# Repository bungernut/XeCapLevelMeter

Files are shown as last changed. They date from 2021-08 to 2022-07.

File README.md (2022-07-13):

# XeCapLevelMeter

This is a demo board and Arduino code for the AD7151 chip:  https://www.analog.com/en/products/ad7151.html  

The board is purchasable from OSHPark  https://oshpark.com/shared_projects/RMe6ks9J  


The arduino code is based on a Teensy 4.1 with Ethernet serving the data over modbus. 
This is still in development and should be expected to be buggy right now.

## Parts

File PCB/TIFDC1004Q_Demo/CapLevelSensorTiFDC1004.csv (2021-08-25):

Source: | C:\Users\bung\Documents\XeCapLevelMeter\PCB\TIFDC1004Q_Demo\CapLevelSensorTiFDC1004.sch
Date: | 8/24/2021 5:48:11 PM
Tool: | Eeschema (5.1.6)-1
Generator: | C:\Program Files\KiCad\bin\scripting\plugins/bom_csv_grouped_by_value.py
Component Count: | 11
Individual Components:
Item | Qty | Reference(s) | Value | LibPart | Footprint | Datasheet | Type
 |  | C1 | 0.1uF | Device:C_Small | Capacitor_SMD:C_0805_2012Metric_Pad1.18x1.45mm_HandSolder | https://www.digikey.com/en/products/detail/08055C104KAT4A/478-10836-1-ND/7536355?itemSeq=374797745 | X7R
 |  | C2 | 1uF | Device:C_Small | Capacitor_SMD:C_0805_2012Metric_Pad1.18x1.45mm_HandSolder | https://www.digikey.com/en/products/detail/885012207051/732-7664-1-ND/5454291?itemSeq=374797744 | X7R
 |  | J1 | Conn_01x02_Female | Connector:Conn_01x02_Female | TerminalBlock_Phoenix:TerminalBlock_Phoenix_PT-1,5-2-3.5-H_1x02_P3.50mm_Horizontal | https://www.digikey.com/en/products/detail/YO0201500000G/609-4725-ND/4242160?itemSeq=374797741
 |  | J2 | Conn_01x02_Female | Connector:Conn_01x02_Female | TerminalBlock_Phoenix:TerminalBlock_Phoenix_PT-1,5-2-3.5-H_1x02_P3.50mm_Horizontal | https://www.digikey.com/en/products/detail/YO0201500000G/609-4725-ND/4242160?itemSeq=374797741
 |  | J3 | Conn_01x02_Female | Connector:Conn_01x02_Female | TerminalBlock_Phoenix:TerminalBlock_Phoenix_PT-1,5-2-3.5-H_1x02_P3.50mm_Horizontal | https://www.digikey.com/en/products/detail/YO0201500000G/609-4725-ND/4242160?itemSeq=374797741
 |  | J4 | Conn_01x02_Female | Connector:Conn_01x02_Female | TerminalBlock_Phoenix:TerminalBlock_Phoenix_PT-1,5-2-3.5-H_1x02_P3.50mm_Horizontal | https://www.digikey.com/en/products/detail/YO0201500000G/609-4725-ND/4242160?itemSeq=374797741
 |  | J5 | Conn_01x04_Male | Connector:Conn_01x04_Male | Connector_PinHeader_2.54mm:PinHeader_1x04_P2.54mm_Vertical | ~
 |  | R1 | 10K | Device:R_Small_US | Resistor_SMD:R_0805_2012Metric_Pad1.20x1.40mm_HandSolder | https://www.digikey.com/en/products/detail/RNCP0805FTD10K0/RNCP0805FTD10K0CT-ND/2240601?itemSeq=374797742
 |  | R2 | 10K | Device:R_Small_US | Resistor_SMD:R_0805_2012Metric_Pad1.20x1.40mm_HandSolder | https://www.digikey.com/en/products/detail/RNCP0805FTD10K0/RNCP0805FTD10K0CT-ND/2240601?itemSeq=374797742
 |  | R3 | 0 | Device:R_Small_US | Resistor_SMD:R_0805_2012Metric_Pad1.20x1.40mm_HandSolder | ~
 |  | U1 | FDC1004 | CapLevelSensorLib:FDC1004 | Package_SO:VSSOP-10_3x3mm_P0.5mm | https://www.digikey.com/en/products/detail/FDC1004QDGSRQ1/296-42334-1-ND/5356920?itemSeq=374797743
Collated Components:
Item | Qty | Reference(s) | Value | LibPart | Footprint | Datasheet | Type
1 | 1 | C1 | 0.1uF | Device:C_Small | Capacitor_SMD:C_0805_2012Metric_Pad1.18x1.45mm_HandSolder | https://www.digikey.com/en/products/detail/08055C104KAT4A/478-10836-1-ND/7536355?itemSeq=374797745 | X7R
2 | 1 | C2 | 1uF | Device:C_Small | Capacitor_SMD:C_0805_2012Metric_Pad1.18x1.45mm_HandSolder | https://www.digikey.com/en/products/detail/885012207051/732-7664-1-ND/5454291?itemSeq=374797744 | X7R
3 | 4 | J1, J2, J3, J4 | Conn_01x02_Female | Connector:Conn_01x02_Female | TerminalBlock_Phoenix:TerminalBlock_Phoenix_PT-1,5-2-3.5-H_1x02_P3.50mm_Horizontal | https://www.digikey.com/en/products/detail/YO0201500000G/609-4725-ND/4242160?itemSeq=374797741
4 | 1 | J5 | Conn_01x04_Male | Connector:Conn_01x04_Male | Connector_PinHeader_2.54mm:PinHeader_1x04_P2.54mm_Vertical | ~
5 | 2 | R1, R2 | 10K | Device:R_Small_US | Resistor_SMD:R_0805_2012Metric_Pad1.20x1.40mm_HandSolder | https://www.digikey.com/en/products/detail/RNCP0805FTD10K0/RNCP0805FTD10K0CT-ND/2240601?itemSeq=374797742
6 | 1 | R3 | 0 | Device:R_Small_US | Resistor_SMD:R_0805_2012Metric_Pad1.20x1.40mm_HandSolder | ~
7 | 1 | U1 | FDC1004 | CapLevelSensorLib:FDC1004 | Package_SO:VSSOP-10_3x3mm_P0.5mm | https://www.digikey.com/en/products/detail/FDC1004QDGSRQ1/296-42334-1-ND/5356920?itemSeq=374797743

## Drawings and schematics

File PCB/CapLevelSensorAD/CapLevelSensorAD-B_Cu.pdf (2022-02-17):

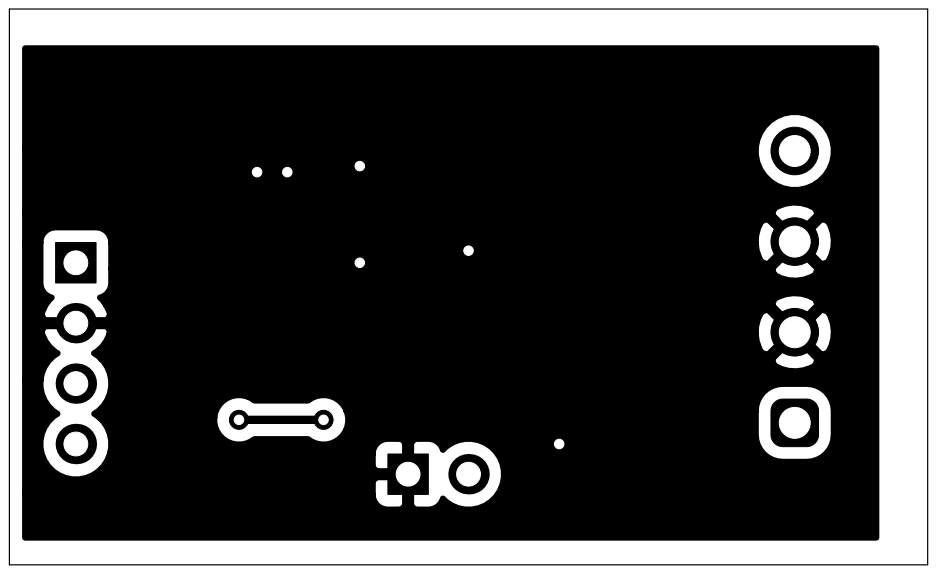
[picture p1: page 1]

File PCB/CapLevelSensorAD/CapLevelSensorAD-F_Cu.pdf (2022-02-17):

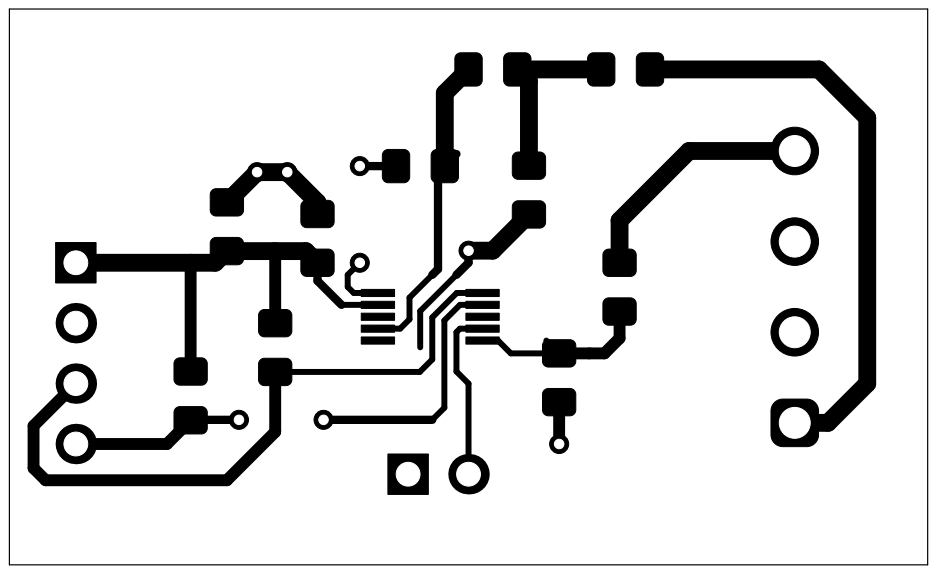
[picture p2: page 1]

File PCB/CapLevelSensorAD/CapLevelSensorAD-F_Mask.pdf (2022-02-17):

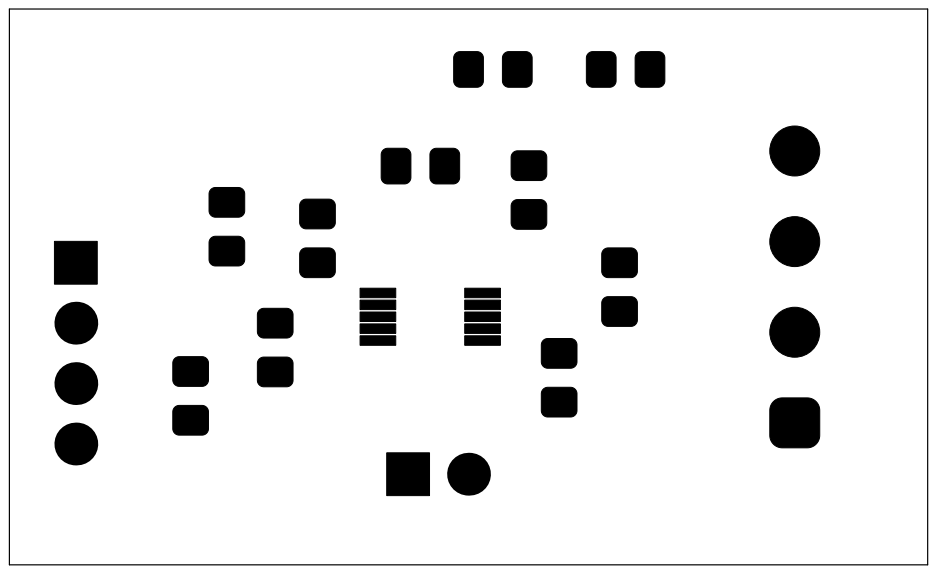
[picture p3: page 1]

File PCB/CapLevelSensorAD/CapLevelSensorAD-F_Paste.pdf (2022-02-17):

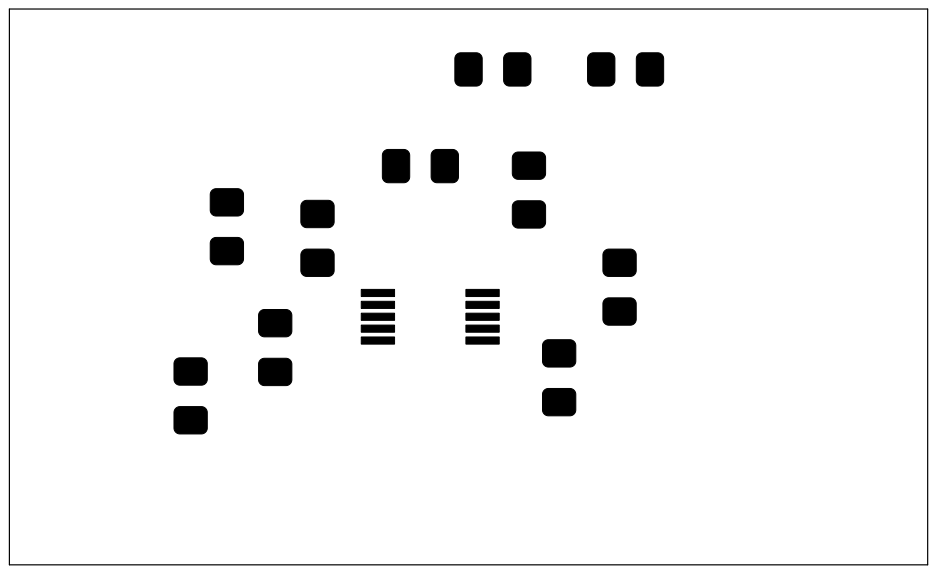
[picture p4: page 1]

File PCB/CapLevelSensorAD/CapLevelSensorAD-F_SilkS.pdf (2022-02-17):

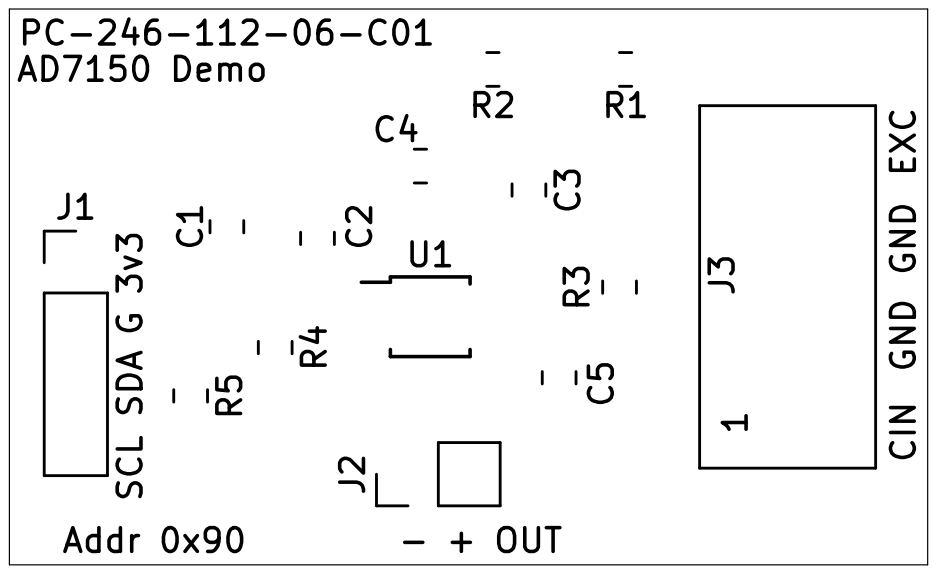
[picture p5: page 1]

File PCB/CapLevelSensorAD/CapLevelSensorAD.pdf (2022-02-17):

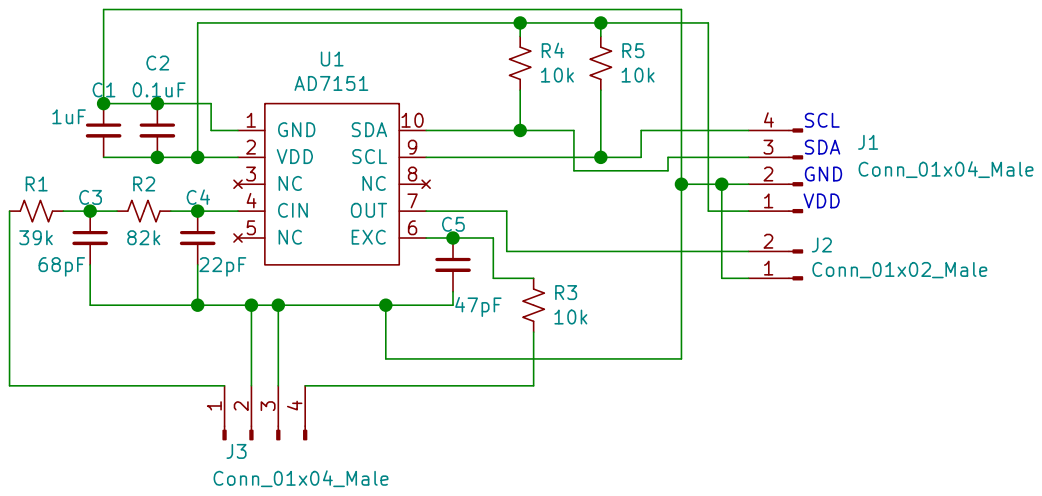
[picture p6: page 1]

File: CapLevelSensorAD.sch Sheet: /
Id: 1/1 Title:

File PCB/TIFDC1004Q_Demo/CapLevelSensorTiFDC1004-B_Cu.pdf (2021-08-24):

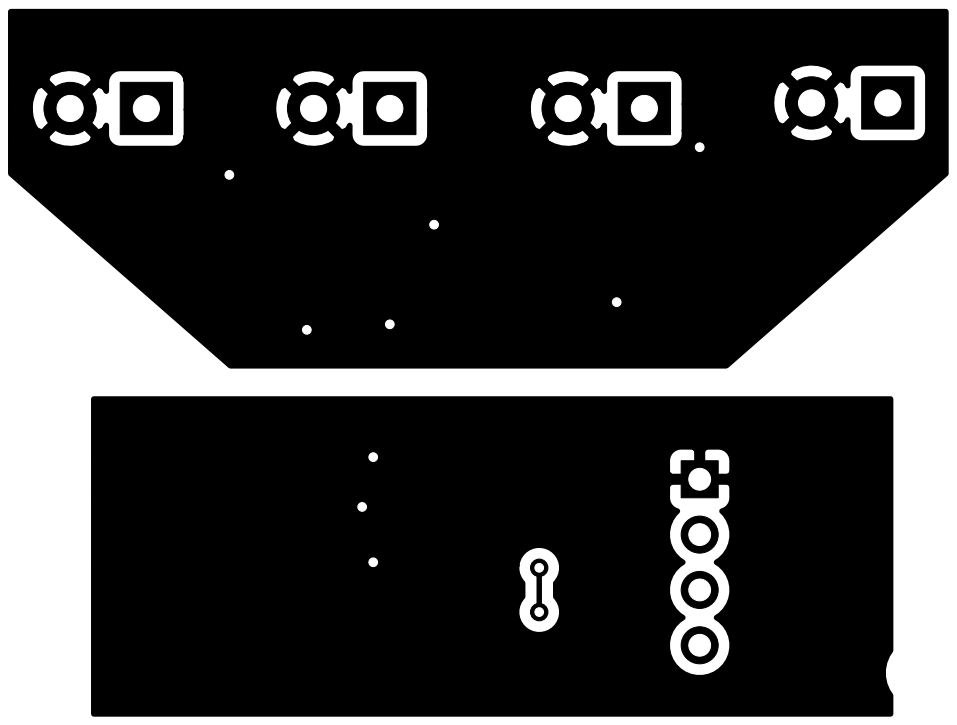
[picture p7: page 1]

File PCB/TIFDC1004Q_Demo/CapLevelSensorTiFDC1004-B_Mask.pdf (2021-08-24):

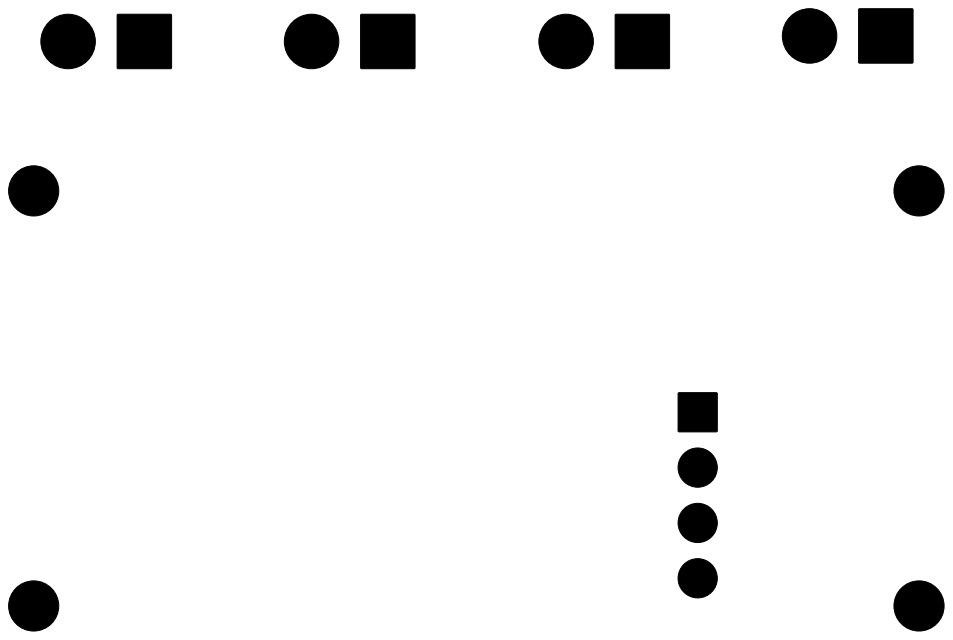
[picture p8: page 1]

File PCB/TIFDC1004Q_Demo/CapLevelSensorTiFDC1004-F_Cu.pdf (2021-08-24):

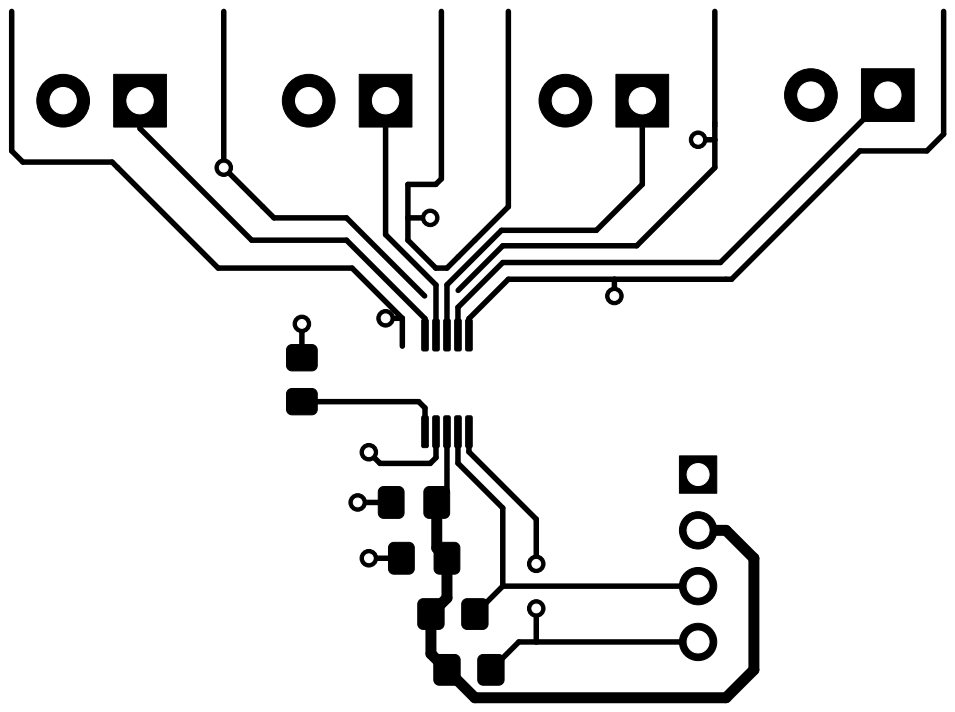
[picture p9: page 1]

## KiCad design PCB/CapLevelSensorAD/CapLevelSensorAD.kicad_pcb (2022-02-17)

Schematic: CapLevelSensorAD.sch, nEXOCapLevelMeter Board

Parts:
C1: 1uF; C_0805_2012Metric_Pad1.15x1.40mm_HandSolder
C2: 0.1uF; C_0805_2012Metric_Pad1.15x1.40mm_HandSolder
C3: 68pF; C_0805_2012Metric_Pad1.15x1.40mm_HandSolder
C4: 22pF; C_0805_2012Metric_Pad1.15x1.40mm_HandSolder
C5: 47pF; C_0805_2012Metric_Pad1.15x1.40mm_HandSolder
J1: Conn_01x04_Male; PinHeader_1x04_P2.54mm_Vertical
J2: Conn_01x02_Male; PinHeader_1x02_P2.54mm_Vertical
J3: Conn_01x04_Male; Amphenol Anytech YO 3.81mm 4p; DigikeyPN 609-3920-ND
R1: 39k; R_0805_2012Metric_Pad1.15x1.40mm_HandSolder
R2: 82k; R_0805_2012Metric_Pad1.15x1.40mm_HandSolder
R3, R4, R5: 10k; R_0805_2012Metric_Pad1.15x1.40mm_HandSolder
U1: AD7151; MSOP-10_3x3mm_P0.5mm; DigikeyPN AD7151BRMZ-ND

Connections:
unnamed: C1.1, C2.1, C3.2, C4.2, C5.2, J1.2, J2.1, J3.2, J3.3, U1.1
unnamed: C1.2, C2.2, J1.1, R4.1, R5.1, U1.2
unnamed: C3.1, R1.1, R2.2
unnamed: C4.1, R2.1, U1.4
unnamed: C5.1, R3.1, U1.6
unnamed: J1.3, R4.2, U1.10
unnamed: J1.4, R5.2, U1.9
unnamed: J2.2, U1.7
unnamed: J3.1, R1.2
unnamed: J3.4, R3.2

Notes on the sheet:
SDA
SCL
GND
VDD

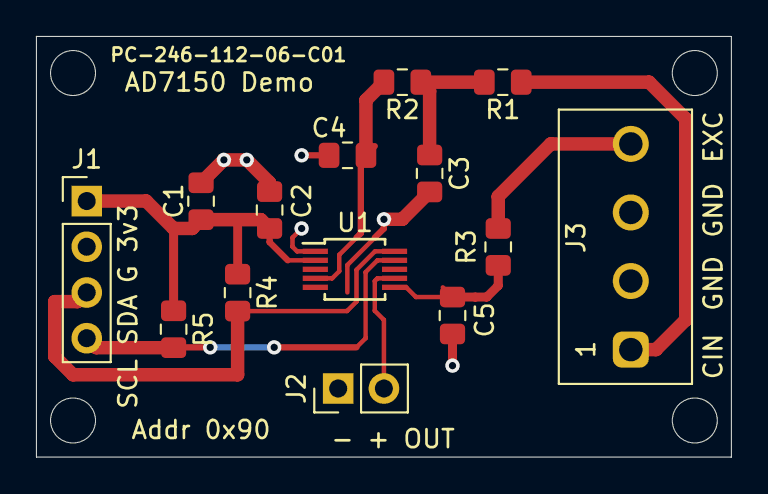
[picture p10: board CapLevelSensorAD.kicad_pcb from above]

Board: 2 copper layers, 38.6 x 23.4 mm, 14 parts (0 on the bottom side), 10 nets.

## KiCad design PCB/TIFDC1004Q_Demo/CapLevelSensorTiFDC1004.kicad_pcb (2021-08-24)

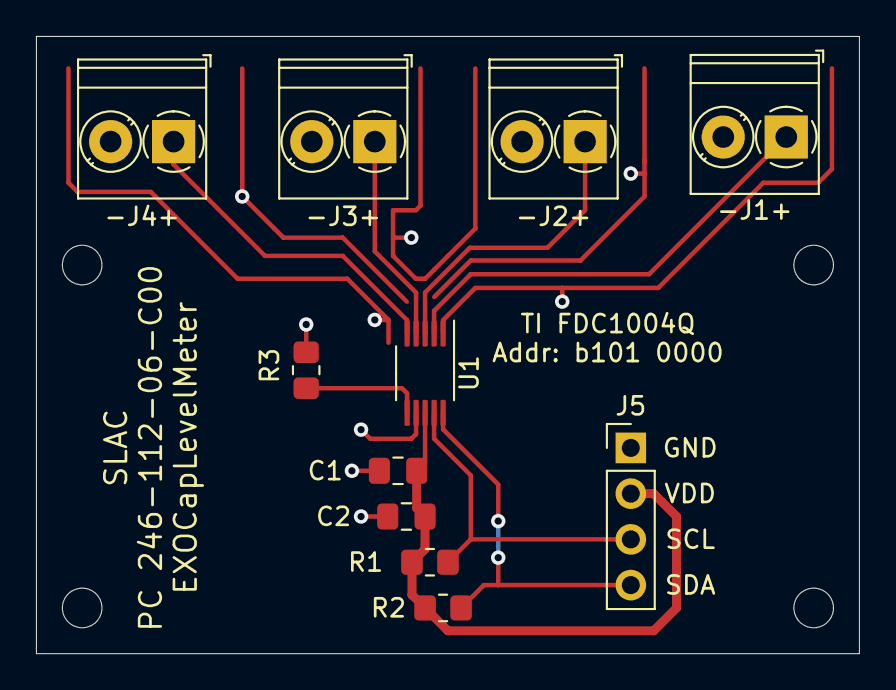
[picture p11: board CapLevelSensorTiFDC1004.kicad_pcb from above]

Board: 2 copper layers, 45.7 x 34.3 mm, 11 parts (0 on the bottom side), 10 nets.

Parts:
-J1+, -J2+, -J3+, -J4+: Conn_01x02_Female; TerminalBlock_Phoenix_PT-1,5-2-3.5-H_1x02_P3.50mm_Horizontal
C1: 0.1uF; C_0805_2012Metric_Pad1.18x1.45mm_HandSolder
C2: 1uF; C_0805_2012Metric_Pad1.18x1.45mm_HandSolder
J5: Conn_01x04_Male; PinHeader_1x04_P2.54mm_Vertical
R1, R2: 10K; R_0805_2012Metric_Pad1.20x1.40mm_HandSolder
R3: 0; R_0805_2012Metric_Pad1.20x1.40mm_HandSolder
U1: FDC1004; VSSOP-10_3x3mm_P0.5mm

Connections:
/GND: C1.2, C2.2, J5.1, U1.7
/SCL: J5.3, R1.1, U1.9
/SDA: J5.4, R2.1, U1.10
/VDD: C1.1, C2.1, J5.2, R1.2, R2.2, U1.8
unnamed: -J1+.1, U1.2
unnamed: -J2+.1, U1.3
unnamed: -J3+.1, U1.4
unnamed: -J4+.1, U1.5
unnamed: R3.2, U1.6
SHLD1: -J1+.2, -J2+.2, -J3+.2, -J4+.2, R3.1, U1.1

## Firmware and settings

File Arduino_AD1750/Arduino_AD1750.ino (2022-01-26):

#include "IO_AD7150.h"

// requires Arduino Modbus library (and dependecies, install with library manager) and modified AD7150 library (included in tar file, place in libraries folder)

IO_AD7150 ad7150;
AD7150_Values result;

#include <SPI.h>
#include <NativeEthernet.h>

#include <ArduinoRS485.h> // ArduinoModbus depends on the ArduinoRS485 library
#include <ArduinoModbus.h>
#define DEBUG1

byte mac[6];

IPAddress ip(192, 168, 1, 177);

EthernetServer ethServer(502);
ModbusTCPServer modbusTCPServer;



void setup()
{
  Serial.begin(115200);

  teensyMAC(mac);
  // uncomment this for DHCP
  // Ethernet.begin(mac);

  // uncomment this for static IP (set above)
  Ethernet.begin(mac,ip);
  


  // Check for Ethernet hardware present
  if (Ethernet.hardwareStatus() == EthernetNoHardware) {
    Serial.println("Ethernet shield was not found.  Sorry, can't run without hardware. :(");
    while (true) {
      delay(1); // do nothing, no point running without Ethernet hardware
    }
  }
  if (Ethernet.linkStatus() == LinkOFF) {
    Serial.println("Ethernet cable is not connected.");
  }

  Serial.print("My IP address: ");
  Serial.println(Ethernet.localIP());

  // start the server
  ethServer.begin();

  // start the Modbus TCP server
  if (!modbusTCPServer.begin()) {
    Serial.println("Failed to start Modbus TCP Server!");
    while (1);
  }

  // configure input registers at address 0x00

  modbusTCPServer.configureInputRegisters(0x00,6);


  // configure capacitance sensor
   
  ad7150.begin();
  ad7150.setOffset( AD7150_OFFSET_AUTO );
  ad7150.setRange(AD7150_RANGE_0_4);
  ad7150.setup();
  
//  uint8_t capdac1 = 0x85;
//  uint8_t capdac2 = 0x97;
//  calibrate(capdac1, capdac2);



  
}

void loop()
{
  ad7150.configure(AD7150_MODE_CONT_CONV);
  delay(10);
  // ad7150.configure(AD7150_MODE_POWER_DOWN); 
  result = ad7150.getValue();
  EthernetClient client = ethServer.available();
  
  if (client) {
    // a new client connected
    // Serial.println("new client");

    // let the Modbus TCP accept the connection 
    modbusTCPServer.accept(client);
    if (client.connected()) {
      // poll for Modbus TCP requests, while client connected
      modbusTCPServer.poll();
    }
  }

 
#ifdef DEBUG1
  Serial.print("Status :");
  Serial.print(result.status, BIN);
  Serial.print("\t");
  Serial.print("Value :");
  Serial.print(result.value, DEC);
  Serial.print(" ");
  Serial.print(result.capdac,DEC);
#endif 

 float cap = 0;
 float offset = 0;

 if (result.value >= 0x3000 and result.value < 0xFFF0 ) {
   cap = ((((float) result.value) - 0x3000) / 0x9ff0) * 4;
   offset = (((float) result.capdac) / 63) * 12.62;
 } 
 
  uint8_t reg = 0;

  modbusTCPServer.inputRegisterWrite(reg++, (uint16_t) ((cap+offset)*1000));
  modbusTCPServer.inputRegisterWrite(reg++, (uint16_t) (cap*1000));
  modbusTCPServer.inputRegisterWrite(reg++, (uint16_t) (offset*1000));
  
  // raw values
  modbusTCPServer.inputRegisterWrite(reg++, (uint16_t) result.value);
  modbusTCPServer.inputRegisterWrite(reg++, (uint16_t) result.capdac);
  modbusTCPServer.inputRegisterWrite(reg++, (uint16_t) result.status);

  
#ifdef DEBUG1   
  Serial.print(" ");
  Serial.print(cap);
  Serial.print(" ");
  Serial.print(offset);
  Serial.print(" ");
  Serial.print(cap+offset); 
  delay(100);
  Serial.println();
#endif 

 

delay(10);
}


void teensyMAC(uint8_t *mac) {
    for(uint8_t by=0; by<2; by++) mac[by]=(HW_OCOTP_MAC1 >> ((1-by)*8)) & 0xFF;
    for(uint8_t by=0; by<4; by++) mac[by+2]=(HW_OCOTP_MAC0 >> ((3-by)*8)) & 0xFF;
    Serial.printf("MAC: %02x:%02x:%02x:%02x:%02x:%02x\n", mac[0], mac[1], mac[2], mac[3], mac[4], mac[5]);
}


float calibrate(uint8_t capdac1, uint8_t capdac2) {

 Serial.print("Calibrating");
 Serial.println();

 ad7150.setOffset(capdac1); 
 ad7150.setup();
 ad7150.configure(AD7150_MODE_SING_CONV);
  delay(10);
  AD7150_Values result1 = ad7150.getValue();
  Serial.print("Status :");
  Serial.print(result1.status, BIN);
  Serial.print("\t");
  Serial.print("Value :");
  Serial.print(result1.value, DEC);
  Serial.print(" ");
  Serial.print(result1.capdac,DEC);

  Serial.println();

  ad7150.setOffset(capdac2); 
  ad7150.setup();
  ad7150.configure(AD7150_MODE_SING_CONV);
  delay(10);
  AD7150_Values result2 = ad7150.getValue();
  Serial.print("Status :");
  Serial.print(result2.status, BIN);
  Serial.print("\t");
  Serial.print("Value :");
  Serial.print(result2.value, DEC);
  Serial.print(" ");
  Serial.print(result2.capdac,DEC);
  Serial.println();

  float cap1 = ((((float) result1.value) - 0x3000) / 0x9ff0) * 4;
  float cap2 = ((((float) result2.value) - 0x3000) / 0x9ff0) * 4;

  
  
  float slope = (cap1 - cap2) / (result2.capdac - result1.capdac);

  Serial.print(slope * 63); 
  Serial.println();

  return slope;
  
  
}

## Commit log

2021-08-24 demo board C00 commit
    [CapLevelSensorTiFDC1004.csv, CapLevelSensorTiFDC1004.kicad_pcb, CapLevelSensorTiFDC1004.sch]
2021-08-25 updating BOM info
    [CapLevelSensorTiFDC1004.csv, CapLevelSensorTiFDC1004.sch]
2022-02-17 adding AD KiCAD files
    [CapLevelSensorAD.kicad_pcb, CapLevelSensorAD.sch]
